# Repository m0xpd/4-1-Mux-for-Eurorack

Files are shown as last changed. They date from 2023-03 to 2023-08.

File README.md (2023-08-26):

# A Dual Channel 4:1 Multiplexer for Eurorack

This project describes a multiplexer (similar to a "sequential switch") for electronic music applications.

<p width=100%, align="center">

</p>

The main system, implemented in a 12HP module, has two 4:1 multiplexers, each of which can switch audio or "CV" signals. The switching can be performed manually, under CV control, or synchronously with an external or internal clock. When clocked, the system can either i) follow the CV input requests (switching synchronously with the clock), ii) advance in a repetitive, finite arithmetic sequence through the inputs or iii) 'shuffle' the inputs randomly. When externally clocked, a "clock divide" feature is available and the system can clock on rising or falling edges of the external clock. The system can be set to cycle (sequentially or randomly) through the first 2, 3 or 4 of the available inputs and can be reset to input 1 on application of an external reset pulse.

The main system also features four potentiometers to generate voltages which are normalled to the 'X' channel inputs of the multiplexer, making it easy to (e.g.) generate CV sequences etc..

Note that, unlike some 'sequential switches' (such as the Doepfer A151), the system is unidirectional; it passes signals only from inputs to outputs. 

The system is based upon a conventional  4052 CMOS analog multiplexer, which is operated between -5V and +5V (to allow safe passage of bipolar signals). Signals are first attenuated (by around 10dB) by passive attenuators before entering the multiplexer and subsequently amplified to restore the signal level. This allows full-scale 'Eurorack' signals to be handled and avoids the non-linearity at the extremes of the multiplexer's transfer characteristic. The system is implemented using Surface Mount components (1206) and the multiplexer switching control is achieved by an Arduino Nano. Although the microcontroller's processing speed will never allow this system to be as fast as pure hardware multiplexers, it has been shown capable of clocking the inputs at frequencies over 2kHz using the code in the 'Controller' folder of this repository (this was with an external clock, of course - the internal clock has been programmed such that the 'rate' control delevers clock frequencies between 0.25 Hz and 13.5 Hz).

The expense of precision resistors for the input attenuators was avoided by measuring and selecting from 1% stock. It was found easy to achieve 0.1% equivalent tolerance in system gain.   

The main multiplexer module draws 25mA from the 12V supply (80% of which is for the Arduino) and 4mA from the -12V supply.

# System Expansion for Multi-Channel Operation

A 'Slave' system, also in 12HP, provides another two channels of multiplexing under the control of the main system. 

<p width=100%, align="center">

</p>

The 'X' channel of the slave unit also has potentiometers offering four voltages to its normalled inputs. 

The slave system is connected to the main system by a ribbon cable, which allows the slave multiplexer to track the switching sequence of the main controller. The slave unit requires an independent eurorack power cable. 

The slave multiplexer module draws 4mA from the 12V supply and 3mA from the -12V supply.

Multiple 'slaves' can be driven by a single main system, allowing 4, 6, 8 ... channel 4:1 mutiplexer systems to be easily constructed - I now run a 6 channel 4:1 mux in my system, using 
a main unit and two slaves...

<p width=100%, align="center">

</p>

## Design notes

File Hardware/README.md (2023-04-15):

This folder contains Eagle files defining the schematics and PCB designs for the main multiplexer and the slave unit.

Kicad projects, describing Front Panels for the main multiplexer and the slave.

Initial versions of the pcbs and the front panels have been fabricated at https://jlcpcb.com/ (usual disclaimer)
who delivered their usual high quality service. 

You can see the result of uploading the main multiplexer pcb gerbers to JLPCB's quote page here: 



There is also an Eagle library for the Thonk Low-profile illuminated push button, used in the design of the main unit for 
manual input selection and current input display. 

low-profile-led-button-main

There is a data sheet at Thonk: https://www.thonk.co.uk/wp-content/uploads/2021/12/LowProfileButton.pdf, but I could find no Eagle library, so I made 
a footprint and a symbol - the former is fine, but the latter is naive and clumsy (as you'll see in the schematic).

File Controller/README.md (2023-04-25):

This folder contains an [Arduino sketch](https://github.com/m0xpd/4-1-Mux-for-Eurorack/blob/main/Controller/Dual_4-1_Mux_Controller.ino) to control the Dual 4:1 Multiplexer.

It isn't pretty, but it works - use it as a foundation on which to build, or start afresh with something new.

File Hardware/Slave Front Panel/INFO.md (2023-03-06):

# This folder contains:

files associated with a Kicad project to build a front panel for the Slave Multiplexer.

The resulting panel looks like this in Kicad's 3D viewer:

Slave Front Panel in 3D Viewer

Panels can be ordered from PCB houses like JLCPCB (https://jlcpcb.com/) for whom an order number locator already is on the bottom (/rear) silkscreen.

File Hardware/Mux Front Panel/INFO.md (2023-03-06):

# This folder contains:

files associated with a Kicad project to build a front panel for the Dual 4:1 Multiplexer main system.

The resulting panel looks like this in Kicad's 3D viewer:

Mux Front Panel in 3D Viewer

Panels can be ordered from PCB houses like JLCPCB (https://jlcpcb.com/) for whom an order number locator already is on the bottom (/rear) silkscreen.

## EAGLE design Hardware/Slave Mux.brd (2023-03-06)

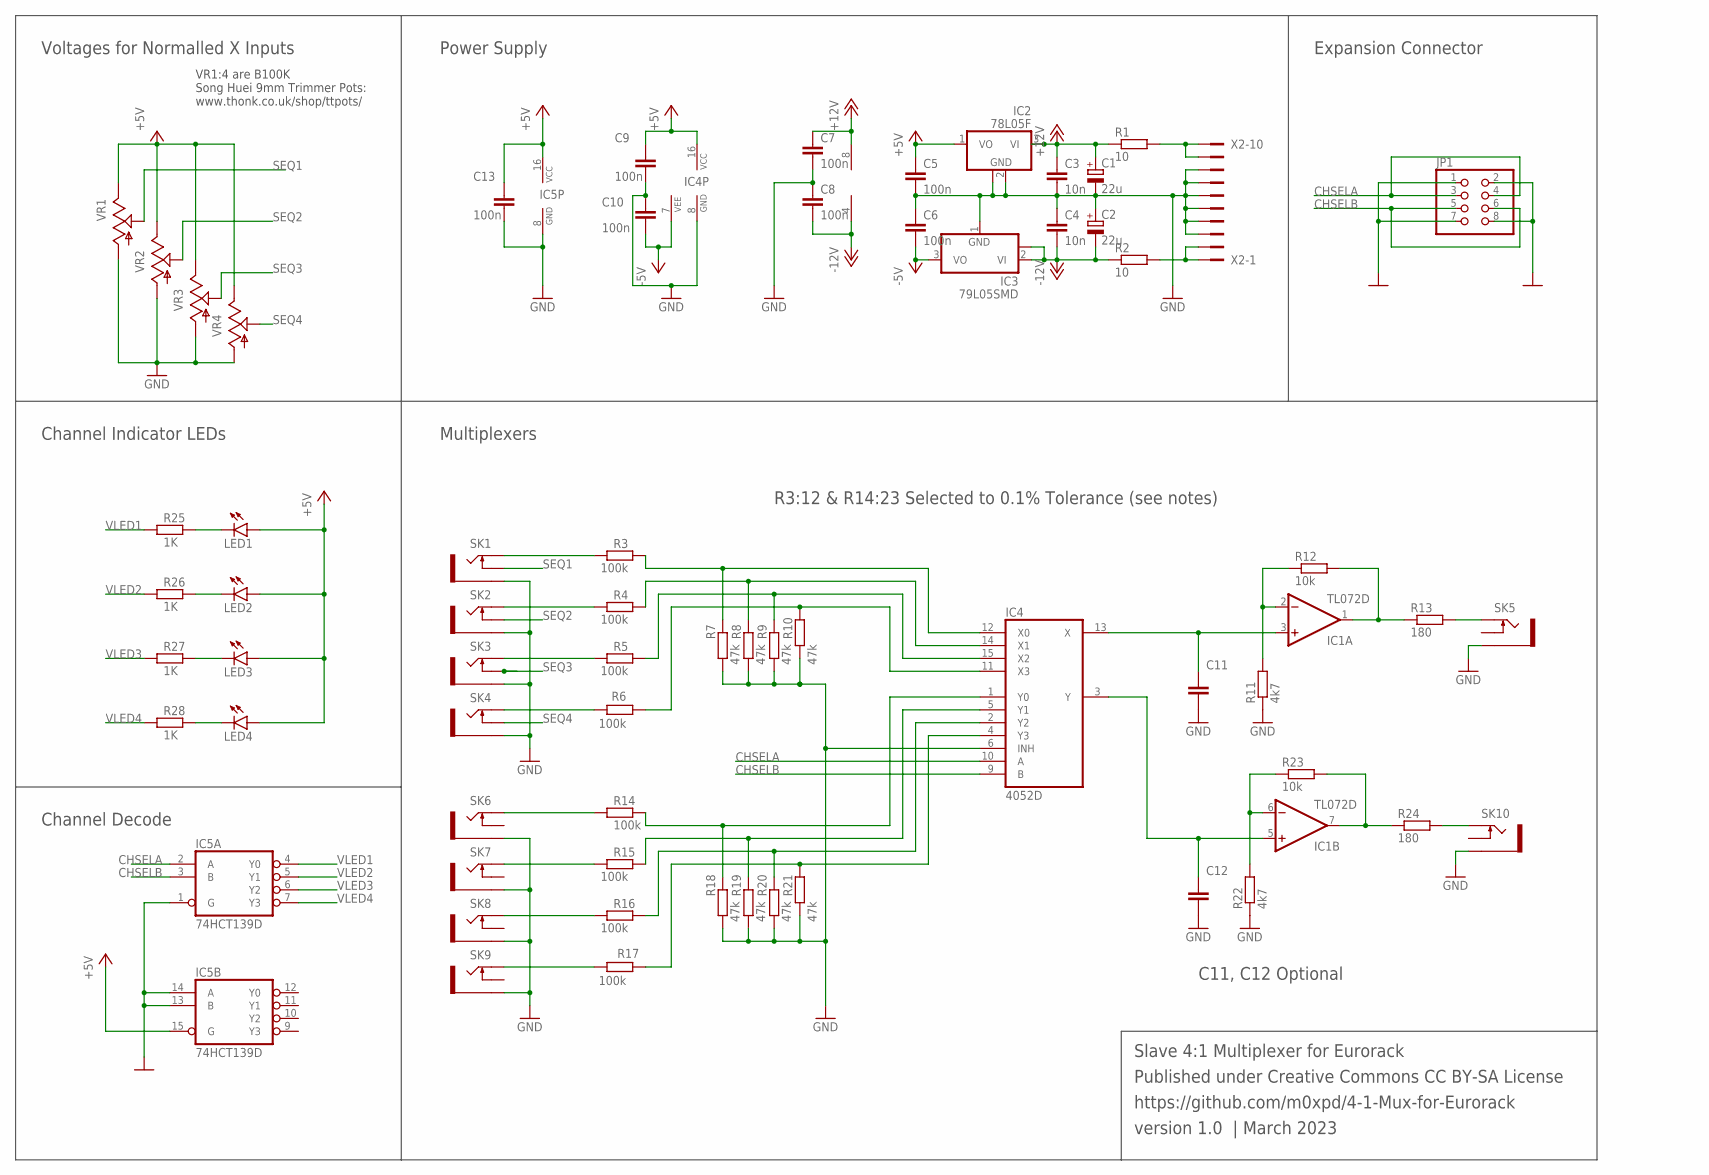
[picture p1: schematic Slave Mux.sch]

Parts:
C1, C2: 22u; 153CLV-0505
C3, C4: 10n; C1206
C5, C6, C7, C8, C9, C10, C13: 100n; C1206
C11, C12: C-EUC1206; C1206
IC1: TL072D; SO08
IC2: 78L05F; SOT89
IC3: 79L05SMD; SOT89
IC4: 4052D; SO16
IC5: 74HCT139D; SO16
JP1: PINHD-2X4; 2X04
LED1, LED2, LED3, LED4: LED3MM
R1, R2: 10; M1206
R3, R4, R5, R6, R14, R15, R16, R17: 100k; M1206
R7, R8, R9, R10, R18, R19, R20, R21: 47k; M1206
R11, R22: 4k7; R1206
R12, R23: 10k; R1206
R13, R24: 180; M1206
R25, R26, R27, R28: 1K; M1206
SK1, SK2, SK3, SK4, SK5, SK6, SK7, SK8, SK9, SK10: THONKICONN_JACK; WQP-PJ301M-12_JACK
VR1, VR2, VR3, VR4: 9MM_VERTICAL_POT; 9MM_SNAP-IN_POT
X2: 2510-; PAK100/2500-10

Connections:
+5V: C5.1, C9.1, C13.1, IC2.1 (VO), IC4.16 (VCC), IC5.15 (G), IC5.16 (VCC), LED1.A, LED2.A, LED3.A, LED4.A, VR1.3 (E), VR2.3 (E), VR3.3 (E), VR4.3 (E)
+12V: C1.+, C3.1, C7.1, IC1.8 (V+), IC2.3 (VI), R1.1
-5V: C6.2, C10.2, IC3.3 (VO), IC4.7 (VEE)
-12V: C2.-, C4.2, C8.2, IC1.4 (V-), IC3.2 (VI), IC3.2@1 (VI), R2.1
CHSELA: IC4.10 (A), IC5.2 (A), JP1.3, JP1.4
CHSELB: IC4.9 (B), IC5.3 (B), JP1.5, JP1.6
GND: C1.-, C2.+, C3.2, C4.1, C5.2, C6.1, C7.2, C8.1, C9.2, C10.1, C11.2, C12.2, C13.2, IC2.2 (GND), IC2.2@1 (GND), IC3.1 (GND), IC4.6 (INH), IC4.8 (GND), IC5.1 (G), IC5.8 (GND), IC5.13 (B), IC5.14 (A), JP1.1, JP1.2, JP1.7, JP1.8, R7.1, R8.1, R9.1, R10.1, R11.1, R18.1, R19.1, R20.1, R21.1, R22.1, SK1.P$3_SLEEVE (SLEEVE), SK2.P$3_SLEEVE (SLEEVE), SK3.P$3_SLEEVE (SLEEVE), SK4.P$3_SLEEVE (SLEEVE), SK5.P$3_SLEEVE (SLEEVE), SK6.P$3_SLEEVE (SLEEVE), SK7.P$3_SLEEVE (SLEEVE), SK8.P$3_SLEEVE (SLEEVE), SK9.P$3_SLEEVE (SLEEVE), SK10.P$3_SLEEVE (SLEEVE), VR1.1 (A), VR2.1 (A), VR3.1 (A), VR4.1 (A), X2.3, X2.4, X2.5, X2.6, X2.7, X2.8
unnamed: IC4.12 (X0), R3.2, R7.2
unnamed: IC4.14 (X1), R4.2, R8.2
unnamed: IC4.15 (X2), R5.2, R9.2
unnamed: C11.1, IC1.3 (+IN), IC4.13 (X)
unnamed: IC1.2 (-IN), R11.2, R12.1
unnamed: IC1.1 (OUT), R12.2, R13.1
unnamed: R3.1, SK1.P$1_TIP (TIP)
unnamed: IC4.11 (X3), R6.1, R10.2
unnamed: R4.1, SK2.P$1_TIP (TIP)
unnamed: R5.1, SK3.P$1_TIP (TIP)
unnamed: R6.2, SK4.P$1_TIP (TIP)
unnamed: LED1.K (C), R25.2
unnamed: R13.2, SK5.P$1_TIP (TIP)
unnamed: IC4.1 (Y0), R14.2, R18.2
unnamed: R1.2, X2.9, X2.10
unnamed: R2.2, X2.1, X2.2
unnamed: IC4.5 (Y1), R15.2, R19.2
unnamed: IC4.2 (Y2), R16.2, R20.2
unnamed: IC4.4 (Y3), R17.1, R21.2
unnamed: R14.1, SK6.P$1_TIP (TIP)
unnamed: R15.1, SK7.P$1_TIP (TIP)
unnamed: R16.1, SK8.P$1_TIP (TIP)
unnamed: R17.2, SK9.P$1_TIP (TIP)
unnamed: LED4.K (C), R28.2
unnamed: C12.1, IC1.5 (+IN), IC4.3 (Y)
unnamed: IC1.6 (-IN), R22.2, R23.1
unnamed: IC1.7 (OUT), R23.2, R24.1
unnamed: R24.2, SK10.P$1_TIP (TIP)
unnamed: LED2.K (C), R26.2
unnamed: LED3.K (C), R27.2
SEQ1: SK1.P$2_SWITCH (SWITCH), VR1.2 (S)
SEQ2: SK2.P$2_SWITCH (SWITCH), VR2.2 (S)
SEQ3: SK3.P$2_SWITCH (SWITCH), VR3.2 (S)
SEQ4: SK4.P$2_SWITCH (SWITCH), VR4.2 (S)
VLED1: IC5.4 (Y0), R25.1
VLED2: IC5.5 (Y1), R26.1
VLED3: IC5.6 (Y2), R27.1
VLED4: IC5.7 (Y3), R28.1

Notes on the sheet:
Slave 4:1 Multiplexer for Eurorack
Published under Creative Commons CC BY-SA License
https://github.com/m0xpd/4-1-Mux-for-Eurorack
version 1.0 | March 2023
R3:12 & R14:23 Selected to 0.1% Tolerance (see notes)
Voltages for Normalled X Inputs
Power Supply
Expansion Connector
Channel Indicator LEDs
Multiplexers
Channel Decode
C11, C12 Optional
VR1:4 are B100K Song Huei 9mm Trimmer Pots: www.thonk.co.uk/shop/ttpots/

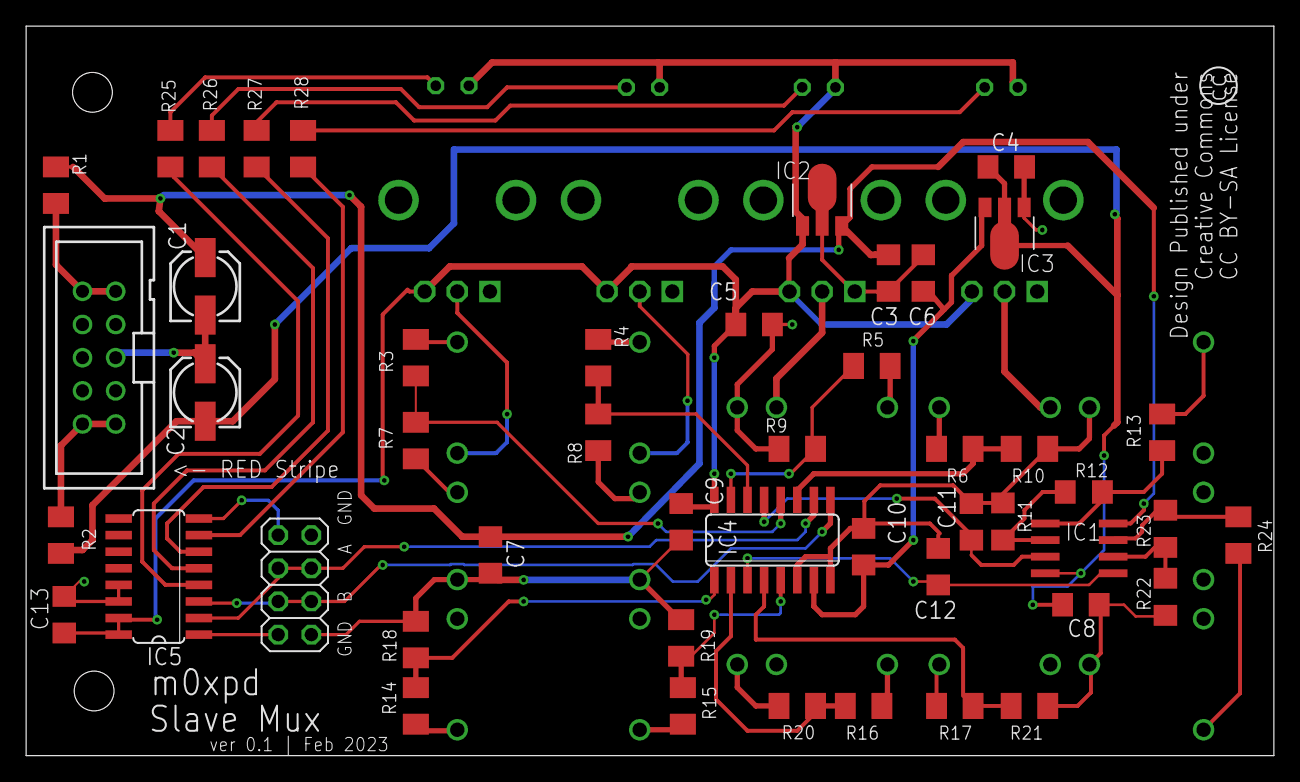
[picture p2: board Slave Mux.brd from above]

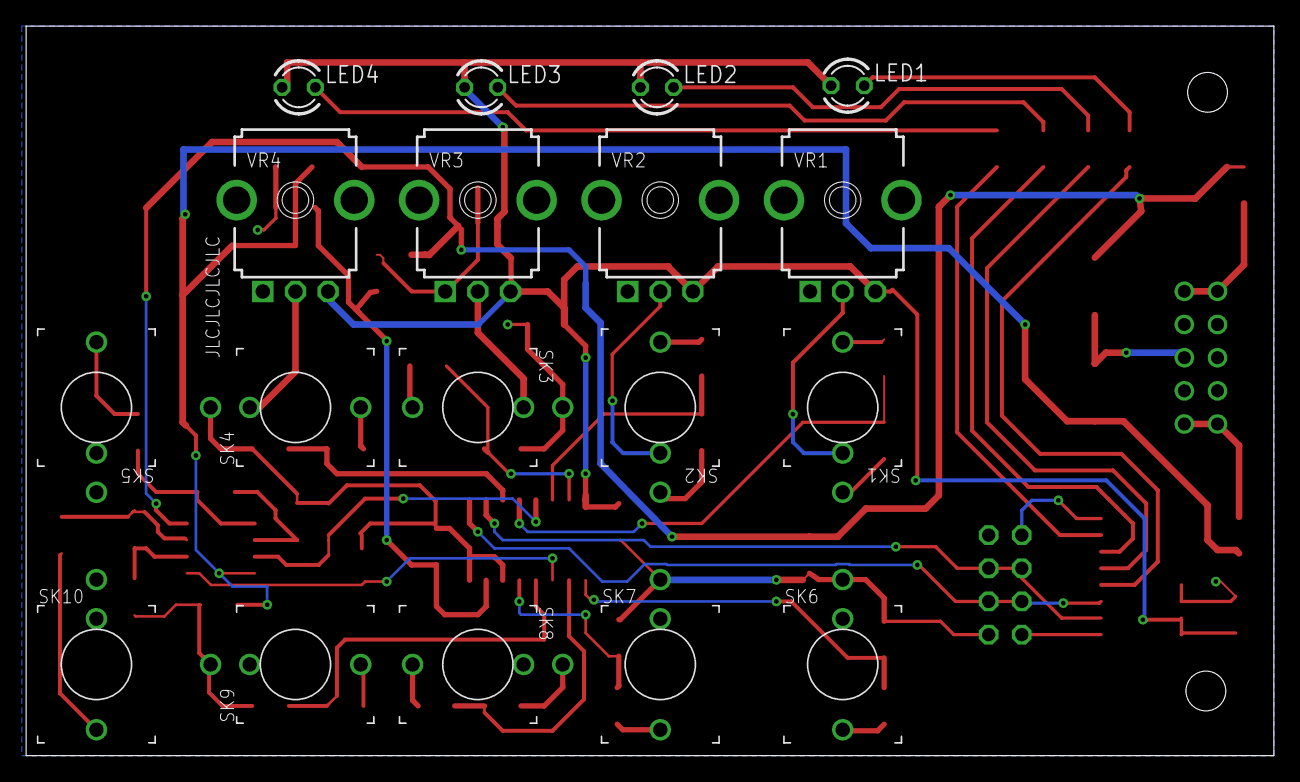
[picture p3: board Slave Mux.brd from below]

Board: 2 copper layers, 95.6 x 55.9 mm, 66 parts (18 on the bottom side), 45 nets.

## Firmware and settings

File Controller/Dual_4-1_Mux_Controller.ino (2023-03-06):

//=================================================
//
//    Dual 4-1 Mux Controller
//    
//    Controller for the m0xpd Dual 4:1 Multiplexer 
//    
//    with:
//      limits on cycle length to
//      2, 3 & 4 steps 
//      (by pressing button1 AND buttonx, x=2,3 or 4)
//    and
//      reset input, 
//      which resets to channel 1
//      on receipt of +ve going pulse on the CVin input 
//      after style of Doepfer A151 
//
//    Published under Creative Commons CC-BY-SA License
//    see https://github.com/m0xpd/4-1-Mux-for-Eurorack
//
//    m0xpd
//    v2.0
//    Feb 2023
//    Last modified 28/2/23  
//   
//==================================================
//
// Hardware Constants
// Pin Allocations
const int  clockPin = 2;          // Digital Input; clock input
const int  channel1Button = 11;   // Digital Input; channel 1 select button
const int  channel2Button = 9;    // Digital Input; channel 2 select button
const int  channel3Button = 7;    // Digital Input; channel 3 select button
const int  channel4Button = 5;    // Digital Input; channel 4 select button
const int  channel1LED = 10;      // Digital Output; channel 1 LED
const int  channel2LED = 8;       // Digital Output; channel 2 LED
const int  channel3LED = 6;       // Digital Output; channel 3 LED
const int  channel4LED = 4;       // Digital Output; channel 4 LED
const int  selA = 12;             // Digital Output; channel select line A
const int  selB = 13;             // Digital Output; channel select line B
const int  clockedIn = A2;        // Digital Input; toggle switch for clocked or free-run
const int  shuffleIn = A4;        // Digital Input; toggle switch for sequential or random
const int  cvcontrolIn = A3;      // Digital Input; toggle switch for CV control
const int  clkSourceIn = A1;      // Digital Input; toggle switch for internal or external clk source
const int  clkDivide = A0;        // Analog Input;  potentiometer for clk divider (ext clock mode) or clk rate (internal clock mode)
const int  cvIn = A7;             // Analog Input;  socket for CV Input (ext control mode) or Reset (cycle mode)

// Variables
int newOCR1A=0;
int newDivide=1;
int scan=1;
int scan2=0;              // second scan variable used otherScan() to read other channel buttons
int channelRequest=0;
int cvchannelRequest = 0;
int channel=1;
int topChannel=4;         // highest channel currently allowed (to limit step number)
int clkCount=0;
int clkMax=1;
int olddivspeed;
int ldivspeed;
int cv=0;
boolean shuffle=false;
boolean cvControl = false;
boolean cvSense = false;
boolean clocked = false;
boolean extclk = false;
boolean resetIn = false;
boolean oldresetIn = false;
boolean diagnostics=false;
boolean resetFlag = false;



void setup() {
setupHardware();
if(diagnostics){
Serial.begin(115200);
}
clocked = digitalRead(clockedIn);
shuffle=!digitalRead(shuffleIn); 
extclk=digitalRead(clkSourceIn);
cvSense=!digitalRead(cvcontrolIn);
if(cvSense){
  cv=analogRead(cvIn);
}
else{
  oldresetIn=digitalRead(cvIn);
}
 // set up internal clock...
  cli();                      
  TCCR1A = 0;                 // Reset entire TCCR1A to 0 
  TCCR1B = 0;                 // Reset entire TCCR1B to 0  
  TCCR1B |= B00000101;        //Set CS12 to 1 -> prescalar 1024   
  TIMSK1 |= B00000010;        //Set OCIE1A to 1 -> compare match A 
  OCR1A = 31250;              // this will be changed as the speed potentiometer is read in readclkdivide()
  sei();  
  readclkdivide();
}

void loop() {
clocked = digitalRead(clockedIn);
shuffle=!digitalRead(shuffleIn); 
extclk=digitalRead(clkSourceIn);
cvSense=!digitalRead(cvcontrolIn);

if(cvSense==false){
  checkReset();
}


scan=digitalRead(channel1Button);
if(scan==0){
  otherScan();
  if(scan2>0){
    topChannel=scan2;
  }
  channelRequest=1;
  changechannel();
}
scan=digitalRead(channel2Button);
if(scan==0){
  channelRequest=2;
  changechannel();
}
scan=digitalRead(channel3Button);
if(scan==0){
  if(topChannel>2){
  channelRequest=3;
  changechannel();
  }
}
scan=digitalRead(channel4Button);
if(scan==0){
  if(topChannel>3){
  channelRequest=4;
  changechannel();
  }
}


if(cvSense){
cv=analogRead(cvIn);  
cvchannelRequest=constrain(floor(cv/256)+1,1,topChannel); 
}
else{
  checkReset();
}

if(clocked){
if(clkCount>=clkMax){
  if(diagnostics){
  Serial.println(clocked); 
  Serial.println(cvSense);
  Serial.println(cvchannelRequest);
  }
  if(cvSense){
    channelRequest=cvchannelRequest;
  }
  else{
    if(shuffle==false){
      channelRequest=channel+1;
        if(channelRequest==topChannel+1){
          channelRequest=1;
      }
    }
    else{
      channelRequest=round(random(1,topChannel+1));
      if(diagnostics){
      Serial.println(channelRequest);
      }
    }
  }
  if(resetFlag==false){
  changechannel();
  }
  else{
  resetFlag=false;
  clkCount=clkMax-1;  
  }
  clkCount=0;
}

// end of clocked
}
else{
// we're not clocked, so clear the clock variables...
clkCount=0;  
if(cvSense){
   channelRequest=cvchannelRequest;
   changechannel(); 
}
if(cvSense==false){
  checkReset();
}

// end of free
}


readclkdivide();
// end of loop
}


void checkReset(){
// Read the cvIn input, 
// which is used as a RESET Input 
// when in local step control (cvSense=false)
 resetIn=bitRead(analogRead(cvIn),9);
 if(resetIn&&(oldresetIn==false)){
  channelRequest=1;
  changechannel();    // just change the channel immediately - even in clocked mode
  resetFlag=true;     // set flag to indicate that the reset operation has been asserted
  clkCount=0;
  oldresetIn=true;
 }
 else{
  oldresetIn=resetIn;
 }
}

void otherScan(){
// Scan the other Buttons (2:4) to support
// multiple button push   
  scan2=0;
  if(digitalRead(channel4Button)==0){
    scan2=4;
  }
  if(digitalRead(channel3Button)==0){
    scan2=3;
  }  
  if(digitalRead(channel2Button)==0){
    scan2=2;
  } 
}


void readclkdivide(){
// Read the rate/divide potentiometer
int divspeed=analogRead(clkDivide);
if (divspeed!=olddivspeed){
  ldivspeed=round(102.4*log(divspeed)/log(2));
  newOCR1A=(1024+20-ldivspeed)*58;
  newDivide=floor(divspeed/64)+1;
  if(extclk==true){
  clkMax=newDivide;
  }
  else{
    clkMax=1;
  }
}
if(diagnostics){
  Serial.println(OCR1A);
  Serial.println(clkMax);
}
olddivspeed=divspeed;  
}


void changechannel(){
// Change the channel  
digitalWrite(channel1LED,LOW);
digitalWrite(channel2LED,LOW);
digitalWrite(channel3LED,LOW);
digitalWrite(channel4LED,LOW); 
switch (channelRequest){
case 1:
digitalWrite(channel1LED,HIGH);
digitalWrite(selA,LOW);
digitalWrite(selB,LOW);
channel=1;
break;
case 2:
digitalWrite(channel2LED,HIGH);
digitalWrite(selA,HIGH);
digitalWrite(selB,LOW);
channel=2;
break;
case 3:
digitalWrite(channel3LED,HIGH);
digitalWrite(selA,LOW);
digitalWrite(selB,HIGH);
channel=3;
break;
case 4:
digitalWrite(channel4LED,HIGH);
digitalWrite(selA,HIGH);
digitalWrite(selB,HIGH);
channel=4;
break;
}
scan=1;
}

void pin_ISR() {
// respond to external clock input interrupts  
  cli();
  if(extclk==true){
  clkCount=clkCount+1;
  clkMax=newDivide;
  }
  sei();
}


ISR(TIMER1_COMPA_vect){
// respond to timer1 interrupts  
  cli();
  OCR1A=newOCR1A;
  TCNT1  = 0;                  //First, set the timer back to 0 so it resets for next interrupt
  if(extclk==false){
  clkCount=clkCount+1;
  clkMax=1;
  }
  sei();
}


void setupHardware(){
// hide all the hardware setup stuff here  
  pinMode(clockPin,INPUT);
  attachInterrupt(digitalPinToInterrupt(clockPin), pin_ISR, RISING); // (this to accord with the polarity of the switched clock signals fed to the system)
pinMode(selA, OUTPUT);
pinMode(selB, OUTPUT);
pinMode(channel1LED, OUTPUT);
pinMode(channel2LED, OUTPUT);
pinMode(channel3LED, OUTPUT);
pinMode(channel4LED, OUTPUT);
pinMode(channel1Button,INPUT_PULLUP);
pinMode(channel2Button,INPUT_PULLUP);
pinMode(channel3Button,INPUT_PULLUP);
pinMode(channel4Button,INPUT_PULLUP);
pinMode(clockedIn,INPUT_PULLUP);
pinMode(shuffleIn,INPUT_PULLUP);
pinMode(cvcontrolIn,INPUT_PULLUP);
pinMode(clkSourceIn,INPUT_PULLUP);
pinMode(clkDivide,INPUT);
pinMode(cvIn,INPUT);
// start on channel 1:
// set initial values of LEDs
digitalWrite(channel1LED,HIGH);
digitalWrite(channel2LED,LOW);
digitalWrite(channel3LED,LOW);
digitalWrite(channel4LED,LOW);
// set initial value of select lines
digitalWrite(selA,LOW);
digitalWrite(selB,LOW);   
}

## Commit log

2023-03-06 Rename Dual 4-1 Mux.brd to Hardware/Dual 4-1 Mux.brd
    [Dual 4-1 Mux.brd]
2023-03-06 Rename Dual 4-1 Mux.sch to Hardware/Dual 4-1 Mux.sch
    [Dual 4-1 Mux.sch]
2023-03-06 Rename Slave Mux.brd to Hardware/Slave Mux.brd
    [Slave Mux.brd]
2023-03-06 Rename Slave Mux.sch to Hardware/Slave Mux.sch
    [Slave Mux.sch]
2023-03-06 Rename Hardware/Dual 4-1 Mux.kicad_pcb to Hardware/Mux Front Panel/Dual 4-1 Mux.kicad_pcb
    [Dual 4-1 Mux.kicad_pcb]
2023-03-06 Rename Hardware/Dual 4-1 Mux.kicad_pro to Hardware/Mux Front Panel/Dual 4-1 Mux.kicad_pro
2023-03-06 Rename Hardware/Dual 4-1 Mux.kicad_sch to Hardware/Mux Front Panel/Dual 4-1 Mux.kicad_sch
    [Dual 4-1 Mux.kicad_sch]
2023-03-06 Rename Hardware/Slave Mux Front Panel.kicad_pcb to Hardware/Slave Front Panel/Slave Mux Front Panel.kicad_pcb
    [Slave Mux Front Panel.kicad_pcb]
2023-03-06 Rename Hardware/Slave Mux Front Panel.kicad_pro to Hardware/Slave Front Panel/Slave Mux Front Panel.kicad_pro
2023-03-06 Rename Hardware/Slave Mux Front Panel.kicad_sch to Hardware/Slave Front Panel/Slave Mux Front Panel.kicad_sch
    [Slave Mux Front Panel.kicad_sch]

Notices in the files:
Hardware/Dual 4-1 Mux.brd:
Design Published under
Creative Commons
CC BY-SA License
